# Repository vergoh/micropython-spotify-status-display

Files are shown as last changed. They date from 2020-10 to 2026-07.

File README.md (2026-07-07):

# micropython-spotify-status-display

MicroPython implementation for ESP32 using a small OLED display to show the "currently playing" information of a Spotify playback device. Two buttons can optionally be added for controlling the playback device. For intended usability, having the buttons is highly recommended.

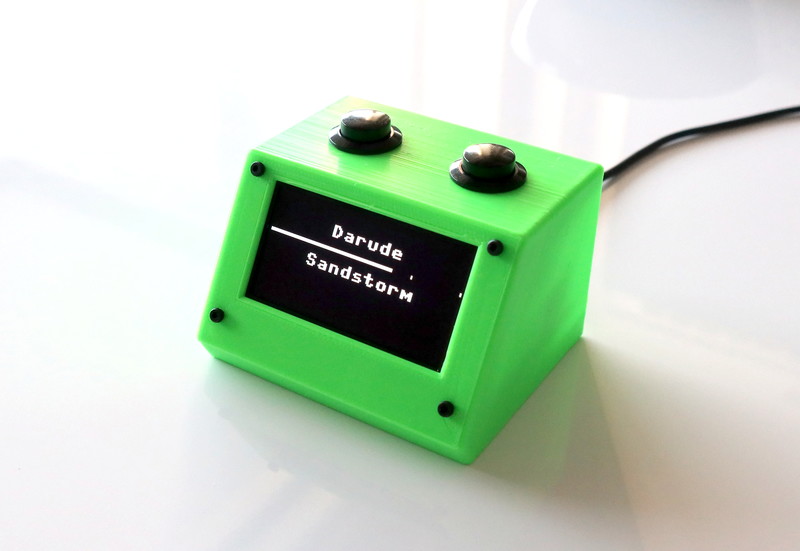
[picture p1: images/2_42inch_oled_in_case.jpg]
2.42" OLED in 3D printed case


## Features

- "currently playing" information with progress bar
  - artist + track
  - show/podcast + episode
- playback control (optional)
  - play / pause
  - next track
  - pause after current track
  - add current track to library
- configurable poll interval and behaviour
- access token stored in device after initial login
- automatic Spotify re-login when refresh token expires
- HTTPS login page with self-signed certificate for Spotify OAuth
- buzzer (optional) for confirming button presses
- screensaver for standby mode
- self contained implementation
- [custom 3D printable case](stl/case.stl) with [lid](stl/lid.stl)

## Requirements

- ESP32 with PSRAM with [MicroPython](https://micropython.org/) 1.23 or later
  - Spotify has enforced HTTPS in callbacks URLs resulting in this version and PSRAM requirement
  - tested with 1.28.0 using Wemos S2 mini
  - previously used Lolin32 Lite board does statisfy these new requirements
- SSD1306 or SSD1309 compatible 128x64 pixel OLED display in i2c mode
  - optional if buttons are only needed / used
  - verified
    - [0.96" SSD1306](https://www.google.com/search?q=128x64+oled+i2c+0.96+ssd1306)
    - [2.42" SSD1309](https://www.google.com/search?q=128x64+oled+i2c+2.42+ssd1309) (recommended)
  - most likely ok
    - [1.3" SSD1306](https://www.google.com/search?q=128x64+oled+i2c+1.3+ssd1306)
  - not verified
    - [1.3" SH1106](https://www.google.com/search?q=128x64+oled+i2c+1.3+sh1106)
- wlan connectivity
- Spotify account
  - Premium needed for playback control
- control buttons (optional)
- buzzer (optional)

See also beginning of [Case.md](Case.md) for a full list of needed components for building the cased solution shown above.

## Limitations

- buttons don't react during api requests / server communication
- buttons require Spotify Premium due to api restrictions
- default font supports mainly us-ascii characters
  - unsupported western characters are however automatically mapped to closest us-ascii equivalents
- playback device isn't aware of the status display resulting in delayed status changes when the playback device is directly controlled

## TODO

- better handling of rare cases of `ECONNABORTED` followed with `EHOSTUNREACH` which gets displayed
- async api requests / server communication (if possible)

## Building it

- [3D printed case build](Case.md) or [DIY wiring](Wiring.md) explains the hardware setup
- [Configuration](Configuration.md) contains the install instructions

## Controls

| | Left button | Right button |
| --- | --- | --- |
| active, short press | play / pause / resume | next track |
| active, long press | save track | pause after current track |
| standby | wake up and resume playback | wake up |

Long press is >= 500 ms by default.

## Included 3rd party implementations

| file | description |
| --- | --- |
| `ssd1306.py` | based on <https://github.com/adafruit/micropython-adafruit-ssd1306> |
| `uurequests.py` | based on <https://github.com/pfalcon/pycopy-lib/blob/master/uurequests/uurequests.py> |
| `helpers.py` | reduced from <https://github.com/blainegarrett/urequests2> |

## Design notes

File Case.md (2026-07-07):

# Case

## DEPRECATED

Lolin32 Lite board suggested below doesn't have the PSRAM needed for getting the implementation running with the TLS requirements Spotify has started enforcing. Using another board, such as Wemos S2 mini, is mandatory but will not properly fit the case design shown below. These instructions will be updated once a new case design is exists.

## Required components

- [Lolin32 Lite](https://www.google.com/search?q=Lolin32+Lite)
- [2.42" SSD1309 based OLED](https://www.google.com/search?q=128x64+oled+i2c+2.42+ssd1309)
- 2 x [R13-507](https://www.google.com/search?q=R13-507) push buttons
- 1 x 6V 470 μF capacitor
- 1 x 6V 100 μF capacitor
- 1 x 10 kΩ resistor
- 4 x M2 hex socket head cap screw, 10-12 mm
  - head cap is visible in the front panel, select accordingly, black hex socket works well
- 2 x M2 hex socket head cap screw, 6-8 mm
  - head cap is hidden under the case and can be anything available
- 6 x M2 nut
- 4 x 2x6 or 2x10 screw (metric, for lid)
- single row 2.54 mm male pin header
  - 4 pins for buttons
  - 5 pins for OLED
  - 2 x 8 pins for Lolin32 Lite (may come with it)
- 2 x 8 pin single row 2.54 mm female pin socket
- 1 x 5 pin single row 2.54 mm female pin header connector
  - for OLED
- 2 x 2 pin single row 2.54 mm female pin header connector
  - for buttons
- 1 x piezo buzzer (optional), 9 mm diameter preferably but 13 mm diamater should also fit
- 1 x [4x6 cm double sided prototype pcb](https://www.google.com/search?q=4x6+cm+double+sided+prototype+pcb)
- 28 AWG (or similar size) wire

Additionally some suitable tools, a soldering iron and access to a 3D printer is needed.

## Printing

Print [case.stl](stl/case.stl) and [lid.stl](stl/lid.stl) using PLA or similar plastic. Use 0.1 - 0.2 mm layer height depending on wanted finish. The case model doesn't need support when printed with the model front facing the bed as shown in the preview. The lid however should be rotated and printed flat.

## OLED I2C setup

The 2.42" SSD1309 based OLED may come by default setup in SPI mode. In that case, the back side of the pcb should look the following:

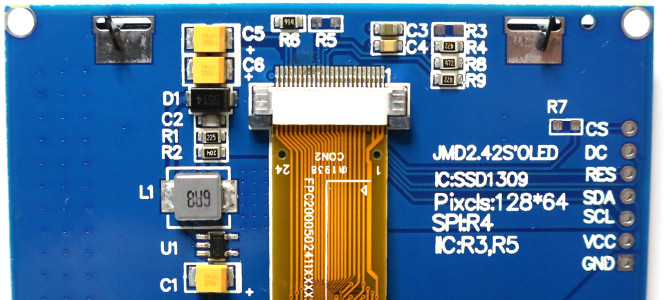
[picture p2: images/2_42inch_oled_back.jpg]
OLED back pcb


For I2C mode, remove the resistor R4 and bridge R3, R5 and R7.

## Assembly

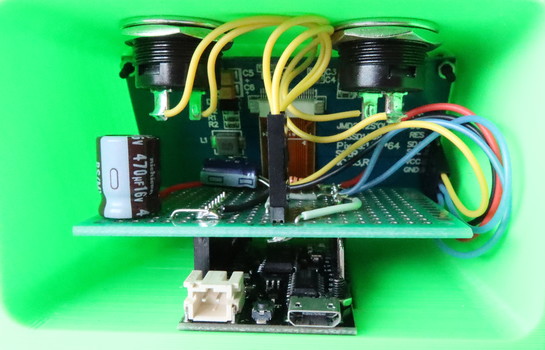
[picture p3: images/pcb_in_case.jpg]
Case from behind


1. Clean the case of any excess plastic left after printing.
2. Attach the OLED to the case using the longer M2 screws and nuts. Don't overtighten.
3. Solder pin headers to Lolin32 Lite with pins facing up. If full length pins headers aren't available then start pins from 3V3 and GND on both sides.
4. Attach female pin header connector on top of pin headers from previous step with pins starting from 3V3 on one side and GND on the other side.
5. Place 4x6 cm prototype pcb on top of female pin header connectors and center the board. The unused empty line should be on the side of the USB connector. Solder the female pin header connectors to the pcb.
6. Wire PCB connections according to below image. Keep the components height low when possible. The 100 μF capacitor should be set on its side while the 470 μF capacitor can stay upright even if built further back than shown in the image. Wires for OLED connector (shown as pin header in the image) can be soldered to connect directly to the source pins or other available locations. Connecting the piezo buzzer shown near the 470 μF capacitor is optional.
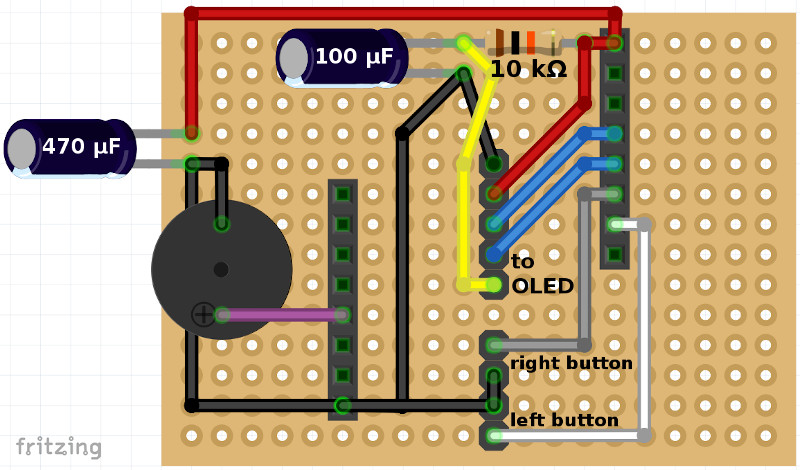
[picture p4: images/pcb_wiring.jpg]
PCB wiring

7. Attach Lolin32 Lite board without the prototype pcb on top of it to the case using the shorter M2 screws / nuts.
8. Connect the display connector from the prototype pcb to the connector on the OLED and attach the prototype pcb on top of Lolin32 lite.
9. Solder wires with connectors to push buttons, make the solder connections face sideways instead of directly down.
10. Attach the push buttons to the case and connect the wires to the prototype pcb.
11. Visually inspect the end result for possible bad connections or extra parts and shake the case to check nothing is loose.
12. Screw the back lid close.

Continue with [Configuration](Configuration.md).

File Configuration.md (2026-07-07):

# Configuration

## Get Spotify client_id and client_secret

1. Login do [Spotify developer dashboard](https://developer.spotify.com/dashboard/login)
2. Select "Create an app"
3. Fill "Status display" or similar as app name, description can be a link to this project or anything else
4. Click "Edit setting" and add `https://spostatus.local/callback/` as "Redirect URI"
   - `spostatus` needs to match the `mdns` name configured in the next section
   - `https://` prefix and `.local/callback/` must remain as shown
   - Spotify requires HTTPS for non-loopback redirect URIs
5. Save the settings dialog
6. Click "Show client secret" and take note of both "Client ID" and "Client Secret"

## Edit src/config.json

1. Fill `client_id` and `client_secret` with values acquired in previous step
2. Fill `pins` section according to used wiring
3. Fill `wlan` section, use `mdns` value selected in previous step

## Generate TLS certificate

1. Run `make cert` (or `make` / `make mpy` to compile and generate certs in one step)
2. This creates ECDSA `prime256v1` `target/cert.pem` and `target/key.pem` for `https://spostatus.local` by default
   - ECDSA certificates use less ESP32 RAM during TLS handshakes than RSA
   - The Makefile `MDNS` variable should match `wlan.mdns` in `src/config.json` if you change the hostname
3. If `mdns` changes later, delete `target/cert.pem` and `target/key.pem`, update `MDNS` in the Makefile if needed, run `make cert`, and update the Spotify redirect URI

## Send implementation and config to device

1. Use MicroPython **1.23 or later** on the ESP32 (HTTPS login requires modern TLS cipher support; tested with 1.28)
2. Transfer the implementation using a serial connection with MicroPython command line
   - **Option 1** - direct source files, higher memory usage:
      1. With MicroPython command line, `put` the content of `src` directory to the root of the device
      2. Also `put` `target/cert.pem` and `target/key.pem` to the root of the device
   - **Option 2** - precompiled binaries, lower memory usage but requires extra step:
      1. With `mpy-cross` installed using `pip`, run `make` to compile the binaries and generate TLS certificates
         - The used `mpy-cross` version needs to match used MicroPython release, see [MicroPython documentation](https://docs.micropython.org/en/latest/reference/mpyfiles.html#versioning-and-compatibility-of-mpy-files) for version compatibility details
      2. With MicroPython command line, `put` the content of `target` directory to the root of the device
         - Possible previously installed `.py` files need to be removed before this step when upgrading
2. Start `repl` and soft reset the device with ctrl-d
3. Fix any possible configuration errors based on shown output
4. Login to Spotify using the device login page:
   1. Open `https://<mdns>.local` in a browser on the same network, for example `https://spostatus.local`
   2. Accept the browser warning for the self-signed certificate
   3. Complete Spotify login and approve the requested permissions
   4. Spotify redirects back to the device automatically

Spotify refresh tokens expire after 6 months from the initial authorization. When this happens, the display shows `login expired`, discards the old token, and starts the login flow again automatically at `https://<mdns>.local`. The device also stores `authorized_at.txt` with the authorization timestamp so expiry warnings can be added later if needed.

If a Spotify device doesn't currently have playback active then the display should reflect the situation. Start playback and the display should react to the change within the configured poll interval.

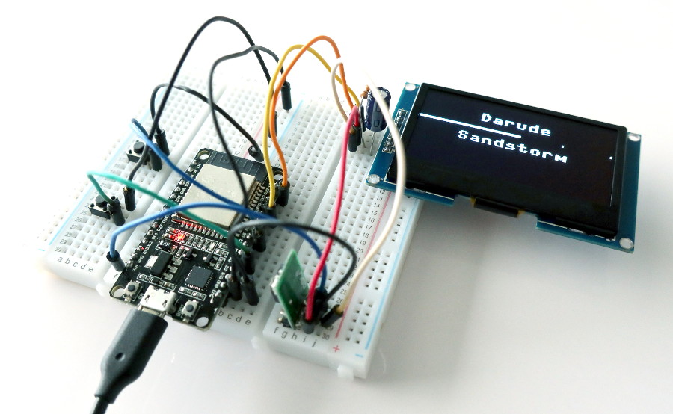
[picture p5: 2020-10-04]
images/prototype.jpg

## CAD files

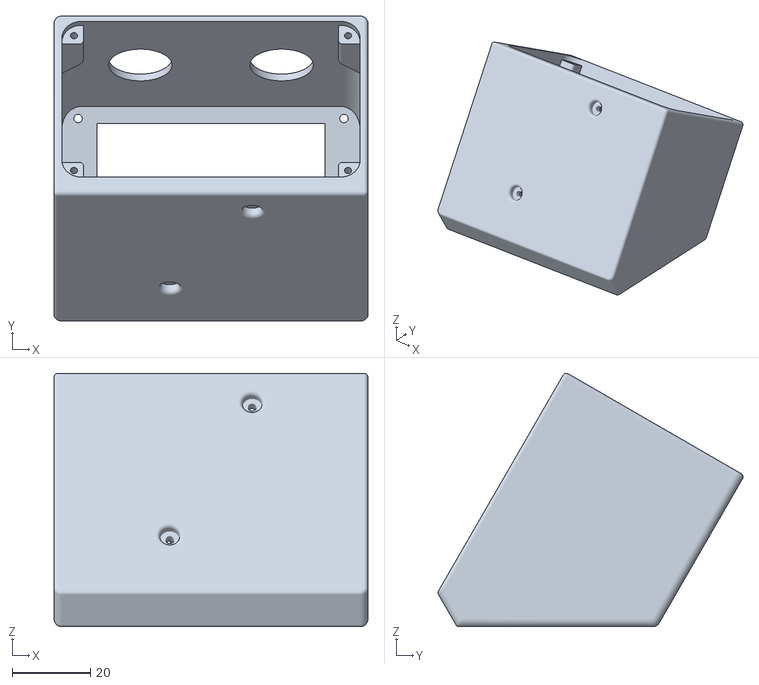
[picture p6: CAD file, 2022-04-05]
stl/case.stl
80.0 x 77.7 x 64.6

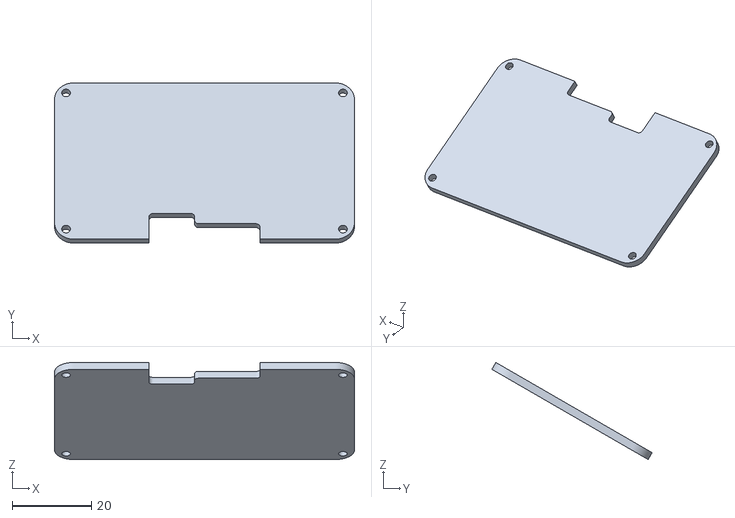
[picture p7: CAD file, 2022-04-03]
stl/lid.stl
75.7 x 40.4 x 24.5

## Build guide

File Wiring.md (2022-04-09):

# Wiring

Example connections for "Lolin32 Lite" pins using a SSD1306 based OLED. Pins may vary on other ESP32 boards. For case build, see [Case.md](Case.md).

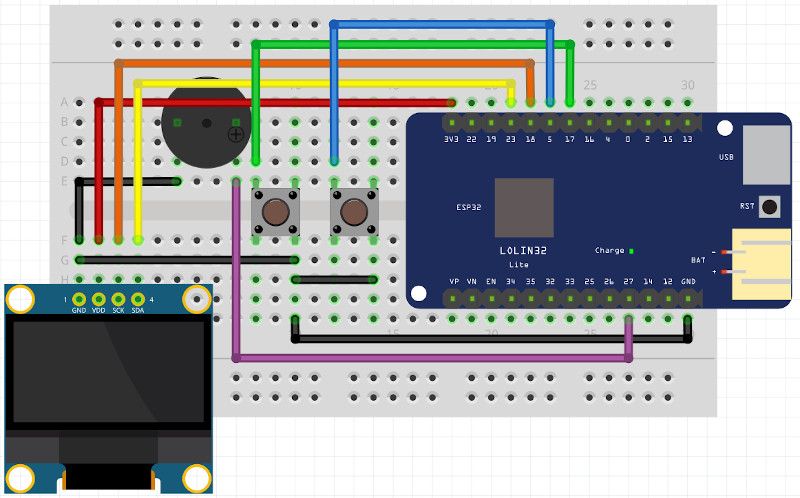
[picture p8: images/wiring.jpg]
Wiring Diagram


## SSD1306 OLED

For 0.96" and 1.3" OLEDs using the SSD1306 chip in i2c mode.

| ESP32 | OLED |
| --- | --- |
| 3V3 | VCC |
| GND | GND |
| 23 | SDA |
| 18 | SCK |

## SSD1309 OLED

For 2.42" OLEDs using the SSD1309 chip in i2c mode, use the same wiring as for the SSD1306 OLED shown above. Note that most of these SSD1309 OLEDs require resistors to be moved for enabling the i2c mode. Additionally, a capacitor of around 220-470 μF is needed between ESP32 3V3 and GND in order to avoid brownout during wlan startup when OLED is being active at the same time. This issue can be seen as a "Brownout detector was triggered" console message followed by a forced reset. Also OLED RES needs to be connected to OLED VCC using a 10 kΩ resistor and to GND using a 10-100 μF capacitor:

| OLED | component | OLED |
| --- | --- | ---
| RES | 10 kΩ resistor | VCC |
| RES | 10-100 μF capacitor | GND |

## Buttons

| ESP32 | button | ESP32 |
| --- | --- | --- |
| D4 | left button | GND |
| D5 | right button | GND |

Button pins need to support internal pullups.

## Piezo Buzzer (Optional)

| ESP32 | Buzzer |
| --- | --- |
| 27 | VCC |
| GND | GND |

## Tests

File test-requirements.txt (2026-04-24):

#
# This file is autogenerated by pip-compile with Python 3.13
# by the following command:
#
#    pip-compile test-requirements.in
#
astroid==4.0.4
    # via pylint
dill==0.4.1
    # via pylint
isort==8.0.1
    # via pylint
mccabe==0.7.0
    # via pylint
platformdirs==4.9.6
    # via pylint
pylint==4.0.5
    # via -r test-requirements.in
tomlkit==0.14.0
    # via pylint

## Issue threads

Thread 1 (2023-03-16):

Does not work with podcasts (TypeError: 'NoneType' object isn't iterable)

ylihemmo, 2023-03-16:
Example of what podcast returns from API:
{'json': {'item': None, 'actions': {'disallows': {'resuming': True}}, 'context': None, 'timestamp': 1678973668576, 'progress_ms': 6149773, 'currently_playing_type': 'episode', 'is_playing': True}, 'text': 'No reply content', 'status_code': 200}

Script ends up in state where None ends up to be iterated and it fails:
TypeError: 'NoneType' object isn't iterable

Quick fix that prevents this and prints 'Podcast' to screen (no podcast or episode name apparently available at the moment from API).

diff from spotify.py:

252a253,255
>         if r['json']['currently_playing_type'] == 'episode':
>             r['json']['item'] = {'podcast': 'true'}
>
343,344c346,351
<             self.oled.show(cp['item'].get('artists', [{}])[0].get('name'), cp['item'].get('name'))
<             await asyncio.sleep(seconds)
---
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

vergoh, 2023-03-16:
`currently_playing_type` already exists in the response as a communication of the playback type, so instead of modifying the response, it would be better to refactor the implementation to use that field as according to the api documentation (https://developer.spotify.com/documentation/web-api/reference/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) it can have any of the following values:
- track
- episode
- ad
- unknown

Stumbled also to https://developer.spotify.com/community/news/2020/03/20/introducing-podcasts-api/ which points out there's a new type parameter for the query which defaults to `track` only and that's why the episode details aren't visible. As a result, instead of using just the `https://api.spotify.com/v1/me/player/currently-playing` endpoint, using `https://api.spotify.com/v1/me/player/currently-playing?additional_types=track,episode` provides the missing details. However, the structure isn't the same for `track` and `episode` so some modifications will still be needed.

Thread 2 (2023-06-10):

RuntimeError: Error 202 - when pressing either of buttons.

ylihemmo, 2023-06-10:
Screen says:
Spotify status
next api error
202

Using:
MicroPython v1.19.1 on 2022-06-18; ESP32 module with ESP32

```
next button pressed
POST https://api.spotify.com/v1/me/player/next
Traceback (most recent call last):
  File "main.py", line 4, in <module>
  File "spotify.py", line 511, in start
  File "uasyncio/core.py", line 1, in run_until_complete
  File "uasyncio/core.py", line 1, in run_until_complete
  File "uasyncio/core.py", line 1, in run_until_complete
  File "spotify.py", line 484, in _looper
  File "spotify.py", line 168, in _handle_buttons
  File "spotify.py", line 308, in _next_playback
  File "spotify.py", line 187, in _validate_api_reply
RuntimeError: Error 202 -
```

Might be user error, but this was working ok earlier.

vergoh, 2023-06-10:
The implementation has been written to support those Spotify API reply status codes that Spotify's own API documentation describes. Everything else results in an error since the behaviour is unspecified by Spotify. For the player/next the documentation is in https://developer.spotify.com/documentation/web-api/reference/skip-users-playback-to-next-track which still shows the possible responses as 204, 401, 403 and 429. For some reason, you got a 202 reply even when the documentation doesn't describe such possibility.

I'll have to check if I can get this issue reproduced and if the same happens also with other API calls. One possible solution could be to add "202" as some sort of "ok enough" status code for all APIs currently supporting 204 (= "no content").

vergoh, 2023-06-10:
Can't reproduce, the response I'm getting is 204 every time. However, that doesn't still mean the problem doesn't exist. https://community.spotify.com/t5/Spotify-for-Developers/Transfer-playback-API-returns-202-instead-of-204/td-p/5517850 suggests the API documentation may not be 100% accurate or up to date. I'll add 202 as a supported reply for those cases where the reply content itself doesn't matter, which should solve the issue of an error getting reported in the cases when the Spotify API doesn't behave exactly as documented.

ylihemmo, 2023-06-10:
Thanks, fixed the issue. For some reason API response for all of these is 202.
next status received: 202
pause status received: 202
resume status received: 202

Closed 2023-06-10.

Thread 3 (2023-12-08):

OSError: [Errno 116] ETIMEDOUT

renatojobal, 2023-12-08:
Hi. Any one can help me? I am getting this error after uploading all files with Micropython and reloading:
```
MPY: soft reboot
no "memdebug" file or directory found, memory debug output disabled
Traceback (most recent call last):
  File "main.py", line 3, in <module>
  File "spotify.py", line 38, in __init__
  File "oled.py", line 15, in __init__
  File "ssd1306.py", line 124, in __init__
  File "ssd1306.py", line 40, in __init__
  File "ssd1306.py", line 65, in init_display
  File "ssd1306.py", line 129, in write_cmd
OSError: [Errno 116] ETIMEDOUT
MicroPython v1.21.0 on 2023-10-05; Generic ESP32 module with ESP32
Type "help()" for more information.
```
I reasearched about the issue but I am not getting a clear answer. Maybe someone had this problem too?

vergoh, 2023-12-08:
Check how you've connected and configured the OLED display. Based on that traceback, the first command sent via i2c fails to result in a reply from the display.

renatojobal, 2023-12-08:
Forget about it, I was using the SSD1315 :/

renatojobal, 2023-12-08:
Thank you anyway :D

vergoh, 2023-12-08:
Search results for SSD1315 are a little bit conflicting if it does work with the same interface as SSD1306 not. Could possibly still be worth a try. Which ESP32 board do you have? Doesn't hurt to a least check the wiring. https://github.com/vergoh/micropython-spotify-status-display/blob/master/Wiring.md is correct for "Lolin32 Lite" but for other boards the correct pins are likely to differ.

renatojobal, 2023-12-09:
Yup, I will try, I would love to contribute If I find a solution.
Btw, I am using this
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

 But now I am facing another error that belongs to another issue.

vergoh, 2023-12-09:
Haven't seen that board before but this appears to be the pinout:
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
You'd want to use the pins columns marked with white background on the pcb. SCL is in GPIO 22, SDA is in GPIO 21 and GND can also be found from the right side. 3V3 can be found from the left side. Led is in GPIO 2.

With this information, the pins part of config.json would look like:
```
	"pins": {
		"led": 2,
		"scl": 22,
		"sda": 21,
		"button_playpause": 18,
		"button_next": 19,
		"buzzer": 23
	},
```
I've mapped here the optional buttons and buzzer to other free pins.

Closed 2024-01-04.

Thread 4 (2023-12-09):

OSError: [Errno 113] ECONNABORTED

renatojobal, 2023-12-09:
I am facing this error:
```
MPY: soft reboot
no "memdebug" file or directory found, memory debug output disabled
buttons enabled
network configured
connected at 192..... as spostatus
listening on ('0.0.0.0', 80) as http://192.... - login at http://spostatus.local
client connected from ('192....', 57234)
GET / HTTP/1.1
not callback path, giving login
client connected from ('192....', 57235)
GET /callback/?code=A... HTTP/1.1
got params: {'code': 'A...'}
reply reports error: None
authorization_code content: A....()
POST https://accounts.spotify.com/api/token
OSError: [Errno 113] ECONNABORTED
failed, retrying...
POST https://accounts.spotify.com/api/token
OSError: -202
token status received: 0
Traceback (most recent call last):
  File "main.py", line 4, in <module>
  File "spotify.py", line 561, in start
  File "asyncio/core.py", line 1, in run_until_complete
  File "asyncio/core.py", line 1, in run_until_complete
  File "asyncio/core.py", line 1, in run_until_complete
  File "spotify.py", line 507, in _looper
  File "spotify.py", line 375, in _initial_token_request
  File "spotify.py", line 234, in _get_api_tokens
  File "spotify.py", line 224, in _validate_api_reply
RuntimeError: token api error 0 - -202
MicroPython v1.21.0 on 2023-10-05; Generic ESP32 module with ESP32
Type "help()" for more information.
```
This happens after I go to the prompted url and accept the permissions.

Btw, I am not using an oled screen, I just commented all the oled part for now. Maybe this could be something?

My Esp32 is this: ESP-WROOM-32 TYPE C (CP2104)
Using Mycropython to load the files
Thony: 4.1.4
Python: 3.10.11

I just have the two buttons connected

Thank you in advance for your reply!

vergoh, 2023-12-09:
https://github.com/vergoh/micropython-spotify-status-display/blob/master/src/spotify.py#L224 is an empty line so you have likely also either added or removed some lines which in turn makes tracking the actual error location harder.

Did you try the login multiple times? Does this same happen every time?

There's always the possibility that something in the Spotify login / api token procedure has changed since the time I wrote the implementation. Once you get the token, there doesn't appear to be anything restricting it to be renewed so I haven't tested this part of the implementation in most likely over half year. If the situation repeats, I can obviously test it out to see if there's indeed some new issue.

The idea of using the implementation with only the buttons but without the oled display is also valid. Probably is wouldn't require too much refactoring to make also the oled configurable as optional and in that case polling the status wouldn't be needed most of the time.

renatojobal, 2023-12-09:
I think it had something to do with the board. I changed the pins as you pointed out in the issue https://github.com/vergoh/micropython-spotify-status-display/issues/3 and now everything works like a charm. Thank you very much!!!

To make the code work with only the button, I just commented out the lines with `self.oled` and added `pass` to the empty `if`` statements. (For that reason the errors appear to be on an empty line, but in reality it was here):
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

I will now attempt to make the OLED screen (SSD1315) work and provide additional comments on that other issue.

Closed 2023-12-13.

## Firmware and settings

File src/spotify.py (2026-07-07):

# MIT License
# Copyright (c) 2020 Teemu Toivola
# https://github.com/vergoh/micropython-spotify-status-display

import gc
import time
import ujson
import network
import uasyncio as asyncio
from machine import Pin
from micropython import const, mem_info

# imports from additional files
import oled
import spotify_api
from buttonpress_async import button_async
from buzzer import buzzer

_app_name = const("Spotify status")

class Spotify:

    def __init__(self):
        self.device_id = None
        self.pause_after_current = False
        self._set_memory_debug()
        self.config = {}
        with open('config.json', 'r') as f:
            self.config = ujson.load(f)

        if self.config['use_led']:
            self.led = Pin(self.config['pins']['led'], Pin.OUT)
            for v in [1, 0, 1]:
                self.led.value(v)
                time.sleep_ms(100)
            self.led.value(0)

        if self.config['use_display']:
            self.oled = oled.OLED(scl_pin = self.config['pins']['scl'], sda_pin = self.config['pins']['sda'], contrast = self.config['contrast'])
            if self.config['low_contrast_mode']:
                self.oled.oled.precharge(0x22)
        else:
            self.oled = oled.OLED(enable = False)
        self.oled.show(_app_name, "__init__", separator = False)

        self._validate_config()

        if self.config['use_buzzer']:
            self.buzzer = buzzer(Pin(self.config['pins']['buzzer'], Pin.OUT), frequency = self.config['buzzer_frequency'], duty = self.config['buzzer_duty'])
            self.buzzer.buzz()
        else:
            self.buzzer = None

        if not self.config['spotify'].get('client_id') or not self.config['spotify'].get('client_secret'):
            self.oled.show(_app_name, "client not configured", separator = False)
            raise RuntimeError("client_id and/or client_secret not configured")

        self.button_playpause = button_async(Pin(self.config['pins']['button_playpause'], Pin.IN, Pin.PULL_UP), long_press_duration_ms = self.config['long_press_duration_milliseconds'], buzzer = self.buzzer)
        self.button_next = button_async(Pin(self.config['pins']['button_next'], Pin.IN, Pin.PULL_UP), long_press_duration_ms = self.config['long_press_duration_milliseconds'], buzzer = self.buzzer)
        print("buttons enabled")

        if self.config['setup_network']:
            self.wlan_ap = network.WLAN(network.AP_IF)
            self.wlan_ap.active(False)
            self.wlan = network.WLAN(network.STA_IF)
            try:
                self.wlan.active(True)
                self.wlan.connect(self.config['wlan']['ssid'], self.config['wlan']['password'])
                self.wlan.config(dhcp_hostname=self.config['wlan']['mdns'])
            except Exception as e:
                self.oled.show(e.__class__.__name__, str(e))
                if str(e) == "Wifi Internal Error" or str(e) == "Wifi Internal State Error":
                    time.sleep(3)
                    import machine
                    machine.reset()
                else:
                    raise
            print("network configured")
        else:
            self.wlan = network.WLAN()
            print("using existing network configuration")

        if self.config['enable_webrepl']:
            import webrepl
            webrepl.start()

        self._wait_for_connection()

        self.ip = self.wlan.ifconfig()[0]
        self.redirect_uri = "https://{}.local/callback/".format(self.config['wlan']['mdns'])

        self.oled.show(_app_name, "__init__ connected {}".format(self.ip), separator = False)
        print("connected at {} as {}".format(self.ip, self.config['wlan']['mdns']))

    def _set_memory_debug(self):
        import os
        self.memdebug = False

        try:
            if os.stat("memdebug") != 0:
                self.memdebug = True
        except Exception:
            pass

        if self.memdebug:
            print("memory debug enabled")
        else:
            print("no \"memdebug\" file or directory found, memory debug output disabled")

    def _validate_config(self):
        boolean_entries = const("use_display,use_led,use_buzzer,setup_network,enable_webrepl,show_progress_ticks,low_contrast_mode,blank_oled_on_standby")
        integer_entries = const("contrast,status_poll_interval_seconds,standby_status_poll_interval_minutes,idle_standby_minutes,long_press_duration_milliseconds,api_request_dot_size,buzzer_frequency,buzzer_duty")
        dict_entries = const("spotify,pins,wlan")
        spotify_entries = const("client_id,client_secret")
        pin_entries = const("led,scl,sda,button_playpause,button_next,buzzer")
        wlan_entries = const("ssid,password,mdns")

        for b in boolean_entries.split(','):
            if b not in self.config or type(self.config[b]) is not bool:
                self._raise_config_error("\"{}\" not configured or not boolean".format(b))

        for i in integer_entries.split(','):
            if i not in self.config or type(self.config[i]) is not int:
                self._raise_config_error("\"{}\" not configured or not integer".format(i))

        for d in dict_entries.split(','):
            if d not in self.config or type(self.config[d]) is not dict:
                self._raise_config_error("\"{}\" not configured or not dict".format(d))

        for s in spotify_entries.split(','):
            if s not in self.config['spotify'] or self.config['spotify'][s] is None or len(self.config['spotify'][s]) < 16:
                self._raise_config_error("\"{}\" not configured or is invalid".format(s))

        for p in pin_entries.split(','):
            if p not in self.config['pins'] or type(self.config['pins'][p]) is not int:
                self._raise_config_error("\"{}\" not configured or is invalid".format(p))

        for w in wlan_entries.split(','):
            if w not in self.config['wlan'] or self.config['wlan'][w] is None or len(self.config['wlan'][w]) < 1:
                self._raise_config_error("\"{}\" not configured or is invalid".format(w))

    def _raise_config_error(self, e):
        self.oled.show("config.json", e)
        raise RuntimeError(e)

    def _wait_for_connection(self):
        was_connected = self.wlan.isconnected()

        if not self.config['use_display'] and not self.wlan.isconnected():
            print("waiting for connection...")

        while not self.wlan.isconnected():
            if self.config['use_display']:
                self.oled.show(_app_name, "waiting for connection", separator = False)
                time.sleep_ms(500)
                self.oled.show(_app_name, "waiting for connection", separator = True)
                time.sleep_ms(500)

        if not was_connected:
            self._reset_button_presses()

    def _reset_button_presses(self):
        self.button_playpause.reset_press()
        self.button_next.reset_press()
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

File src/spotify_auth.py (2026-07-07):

# MIT License
# Copyright (c) 2023 Teemu Toivola
# https://github.com/vergoh/micropython-spotify-status-display

import gc
import socket
import select
import ssl
from helpers import quote, urlencode

CERT_FILE = 'cert.pem'
KEY_FILE = 'key.pem'
HTTPS_PORT = 443

def _cert_files_present():
    for cert_file in (CERT_FILE, KEY_FILE):
        try:
            with open(cert_file, 'r') as f:
                if f.read(1) == '':
                    return False
        except OSError:
            return False
    return True

def _load_tls_credentials():
    try:
        with open(CERT_FILE, 'rb') as f:
            cert = f.read()
        with open(KEY_FILE, 'rb') as f:
            key = f.read()
    except OSError as e:
        print("failed to read TLS credentials: {}".format(e))
        return None, None

    if not cert or not key:
        print("TLS certificate files are empty: {} and {}".format(CERT_FILE, KEY_FILE))
        return None, None

    return cert, key

def _read_line(sock):
    line = b''
    while not line.endswith(b'\r\n'):
        chunk = sock.read(1)
        if not chunk:
            return None
        line += chunk
    return line

def _read_request_path(sock):
    line = _read_line(sock)
    if line is None:
        return None

    if line.startswith(b'GET '):
        print(line.decode().strip())
        parts = line.decode().strip().split(' ')
        if len(parts) >= 2:
            reqpath = parts[1]
        else:
            reqpath = None
    else:
        reqpath = None

    while True:
        line = _read_line(sock)
        if line is None or line == b'\r\n':
            break

    return reqpath

def _send_response(sock, status, content_type, body):
    if isinstance(body, str):
        body = body.encode()
    header = 'HTTP/1.0 {}\r\nContent-type: {}\r\n\r\n'.format(status, content_type)
    sock.write(header.encode())
    sock.write(body)

def get_authorization_code(client_id, redirect_uri, mdns):
    if not _cert_files_present():
        print("TLS certificate files missing: {} and {}".format(CERT_FILE, KEY_FILE))
        print("Run make cert and deploy both files to the device")
        return None

    cert, key = _load_tls_credentials()
    if cert is None:
        return None

    spotify_auth_url = "https://accounts.spotify.com/authorize"
    scopes = "user-read-currently-playing user-read-playback-state user-modify-playback-state user-library-modify"

    user_login_url = "{}?{}&scope={}".format(
        spotify_auth_url,
        urlencode({
            'client_id': client_id,
            'response_type': 'code',
            'redirect_uri': redirect_uri,
        }),
        quote(scopes),
    )
    print("authorize scope param: {}".format(quote(scopes)))

    addr = socket.getaddrinfo('0.0.0.0', HTTPS_PORT)[0][-1]
    http_server = socket.socket()
    http_server.bind(addr)
    http_server.listen(1)
    serv_counter = 0
    callback_code = None

    print("listening for login at https://{}.local".format(mdns))

    while True:
        read_sockets = [http_server]
        (r, _, _) = select.select(read_sockets, [], [])

        if http_server in r:
            reqpath = None
            cl, client_addr = http_server.accept()
            print("client connected from {}".format(client_addr))
            gc.collect()
            try:
                cl = ssl.wrap_socket(cl, server_side=True, cert=cert, key=key)
            except (OSError, ValueError) as e:
                print("TLS handshake failed: {}".format(e))
                cl.close()
                gc.collect()
                continue

            reqpath = _read_request_path(cl)

            if reqpath is not None and reqpath.startswith('/callback') and '?' in reqpath:
                reqparams = reqpath.split('?')[1]
                params = {}
                for reqparam in reqparams.split('&'):
                    p = reqparam.split('=')
                    if len(p) != 2:
                        continue
                    params[p[0]] = p[1]
                print("got params: {}".format(params))
                if 'code' in params:
                    _send_response(cl, '200 OK', 'text/html', "<html><head><title>Login complete</title></head><body>Login complete, this page can now be closed</body></html>\r\n")
                    cl.close()
                    callback_code = params.get('code')
                    break
                elif 'error' in params:
                    oauth_error = params.get('error')
                    oauth_description = params.get('error_description', '')
                    print("oauth error: {} {}".format(oauth_error, oauth_description))
                    error_page = (
                        "<html><head><title>Login error</title></head><body>"
                        "<p>Spotify login failed: {}</p>"
                        "<p><a href=\"/\">Try again</a></p>"
                        "</body></html>\r\n"
                    ).format(oauth_error)
                    _send_response(cl, '200 OK', 'text/html', error_page)
                    cl.close()
                    continue
                else:
                    _send_response(cl, '200 OK', 'text/html', "<html><head><title>Login error</title></head><body>Missing authorization code. <a href=\"/\">Try again</a></body></html>\r\n")
                    cl.close()
                    continue
            elif reqpath is not None and reqpath == '/':
                print("not callback path, giving login")
                login_page = "<head><title>Redirect to login</title><meta http-equiv=\"Refresh\" content=\"0; URL={}\"></head>".format(user_login_url)
                _send_response(cl, '200 OK', 'text/html', login_page)
                cl.close()
            else:
                print("unknown path, sending 404")
                _send_response(cl, '404 Not Found', 'text/plain', "Not Found\r\n")
                cl.close()

            serv_counter += 1
            if serv_counter == 5:
                print("counter limit reached")
                break

    http_server.close()
    del cert, key
    gc.collect()

    return callback_code

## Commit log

2020-09-29 add pylint, fix findings and enable Travis CI
    [buttonpress_async.py, helpers.py, spotify.py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]
2020-09-30 add wiring diagram image
2020-10-04 add wiring documentation for 2.42 inch SSD1309 OLED and add current breadboard prototype picture
2020-10-05 improve api response (or the lack of it) handling based on seen issue
    [spotify.py, spotify_api.py]
2020-11-12 add 3d printable case stl file, no back wall in current design
    [case.stl]
2020-11-12 remove use_buttons as useless, wait for wlan reconnection if connectivity is lost, improve requests connectivity error handling, resume playback from standby directly if play/pause button is pressed 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
    [spotify.py, spotify_api.py]
2020-11-13 handle 403 reply from resume api as warning instead of error
    [spotify.py]
2020-11-18 replace characters not supported by the oled font with question marks instead of letting variable width blocks being made visible
    [oled.py]
2022-02-04 improve memory management and error handling/reporting, removes/reduces not playing messages during playback
    [oled.py, spotify.py, spotify_api.py]
2022-02-13 fix possible NameError situation, increase duration of warnings shown on oled from 3 seconds to 5 seconds
    [spotify.py, spotify_api.py]
2022-04-03 add lid to case
    [case.stl, lid.stl]
2022-04-05 minor internal cosmetic changes to case design, round few sharp edges and restore symmetry
    [case.stl]
2022-04-09 add support for optional buzzer for confirming button presses
    [buzzer.py, spotify.py]
2023-03-16 add support for shows/podcasts (closes #1), improve initial access token handling to avoid lack of expires_in information
    [spotify.py, spotify_api.py]
2023-06-10 handle Spotify API rarely giving a 202 reply instead of the expected 204, harmonize status prints in console output, resolves #2
    [spotify.py]
2023-06-14 refactor to improve memory usage, add handler for Wifi Internal Error after soft reset, add optional memory debug output, add make target for precompiling binaries, document optional use of precompil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
    [spotify.py, spotify_api.py, spotify_auth.py]
2023-07-11 fix standby sometimes stopping polling for status changes
    [buttonpress_async.py, spotify.py]
2023-07-24 long press of next button pauses playback after current track, rename textwrap as textutils to avoid possible conflicts
    [oled.py, spotify.py, textutils.py]
2024-01-04 improve button responsiveness, beep again when long press is detected while button is still pressed
2026-04-24 update github actions versions, upgrade pylint and fix findings
    [spotify.py, uurequests.py]
2026-07-07 add support for Spotify expiring renew tokens after 6 months, migrate callback to use https instead of http with self-signed certificate, update micropython version requirements due to tls support, u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
2026-07-07 add handler for changed wifi internal error
    [spotify.py]
2026-07-07 replace deprecated Spotify save track endpoint
    [spotify_api.py]
